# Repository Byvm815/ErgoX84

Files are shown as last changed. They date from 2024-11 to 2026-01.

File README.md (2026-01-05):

# ErgoX Keyboard

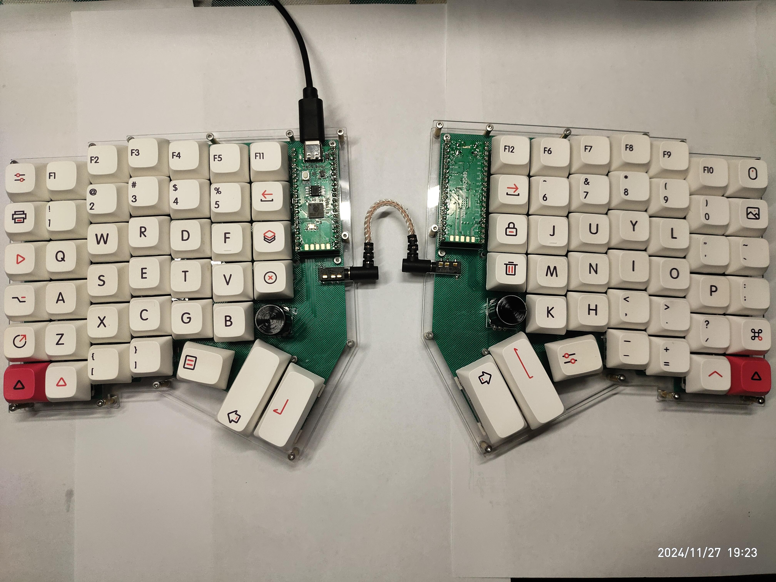
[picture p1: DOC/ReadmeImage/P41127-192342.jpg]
Preview


## BOM Summary

| Product | Count |
|---|---|
| RP2040 type-c Board | 2 |
| Switch | 82 |
| Switch Connector | 82 |
| EC11 Encoder | 2 |
| 1N4148WS T4 | 84 |
| TRRS Cable | 1 |
| TRRS Connector | 2 |
| 2.54-1*20 Connector Female | 4 |
| Switch Board | 2 |
| Bottom Board | 2 |
| Stabilizer 2U | 6 |
| M2 * 3mm Copper Column | 16 |
| M2 * 8mm Copper Column | 50 |
| M2 * 3mm Screw | 132 |

Key caps:

| Key Cap Type  | Count |
|---|---|
| 1U | 68 |
| 1.25U | 4 |
| 1.5U | 2 |
| 1.75U | 2 |
| 2U | 4 |
| 2.25U | 2 |
| EC11 knob cap | 2 |

## Layout

Edited using [Keyboard-Layout-Editor.com](https://keyboard-layout-editor.com/)

Layout files:

- for generating `vial.json`: [keyboard-layout-full-vial-12r7c.json](./keyboard-layout-full-vial-12r7c.json)
- for designing PCB and Case: [keyboard-layout-left.json](./keyboard-layout-left.json)

## Case

Generated using [Plate & Case Builder](http://builder.swillkb.com/), and then edited
using [LibreCAD](https://github.com/LibreCAD/LibreCAD).

Files:

- [Switch board](./case/switch.dxf)
- [Bottom board](./case/bottom.dxf)
- [PCB border and document](./case/pcb.dxf) (only used for PCB designing)

```plaintext
---------------------------- switch board
  | 8mm copper column
  |  ------------------- PCB
  |   | 3mm copper column
---------------------------- bottom board
```

## PCB

Designed using [JLC EDA](https://lceda.cn/editor).

PCB Project: [https://oshwhub.com/lqlklu/ergox](https://oshwhub.com/lqlklu/ergox)

## Firmware

Based on [RMK](https://github.com/HaoboGu/rmk/).

- [./firmware/ergox_conf](./firmware/ergox_conf): using `keyboard.toml` config file, works well
- [./firmware/ergox_rs](./firmware/ergox_rs): using rust code, for testing and do not work now

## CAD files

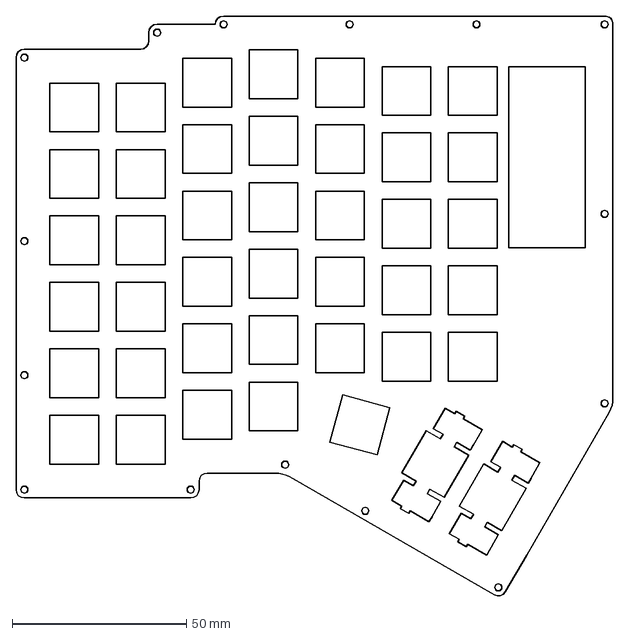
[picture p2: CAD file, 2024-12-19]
case/Switch_ErgoX84_2024-12-09.dxf
171.2 x 166.6 mm

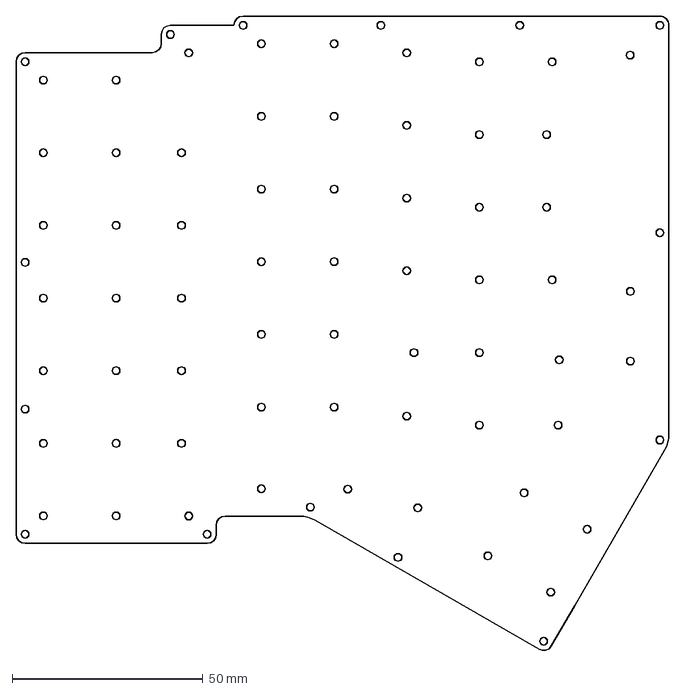
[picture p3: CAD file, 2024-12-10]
case/Bottom_ErgoX84_2024-12-09.dxf
171.2 x 166.6 mm

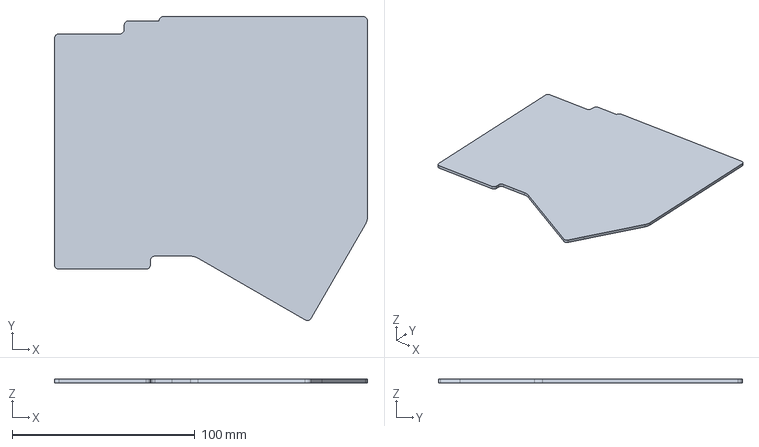
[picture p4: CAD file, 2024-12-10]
case/PCB_ErgoX84_2024-12-09.FCStd
171.2 x 166.3 x 2.00 mm

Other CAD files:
case/PCB_ErgoX84_2024-12-09.dxf

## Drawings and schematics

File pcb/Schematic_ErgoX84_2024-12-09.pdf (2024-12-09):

All document translations are completed by ChatGPT and are for reference only.

L | R

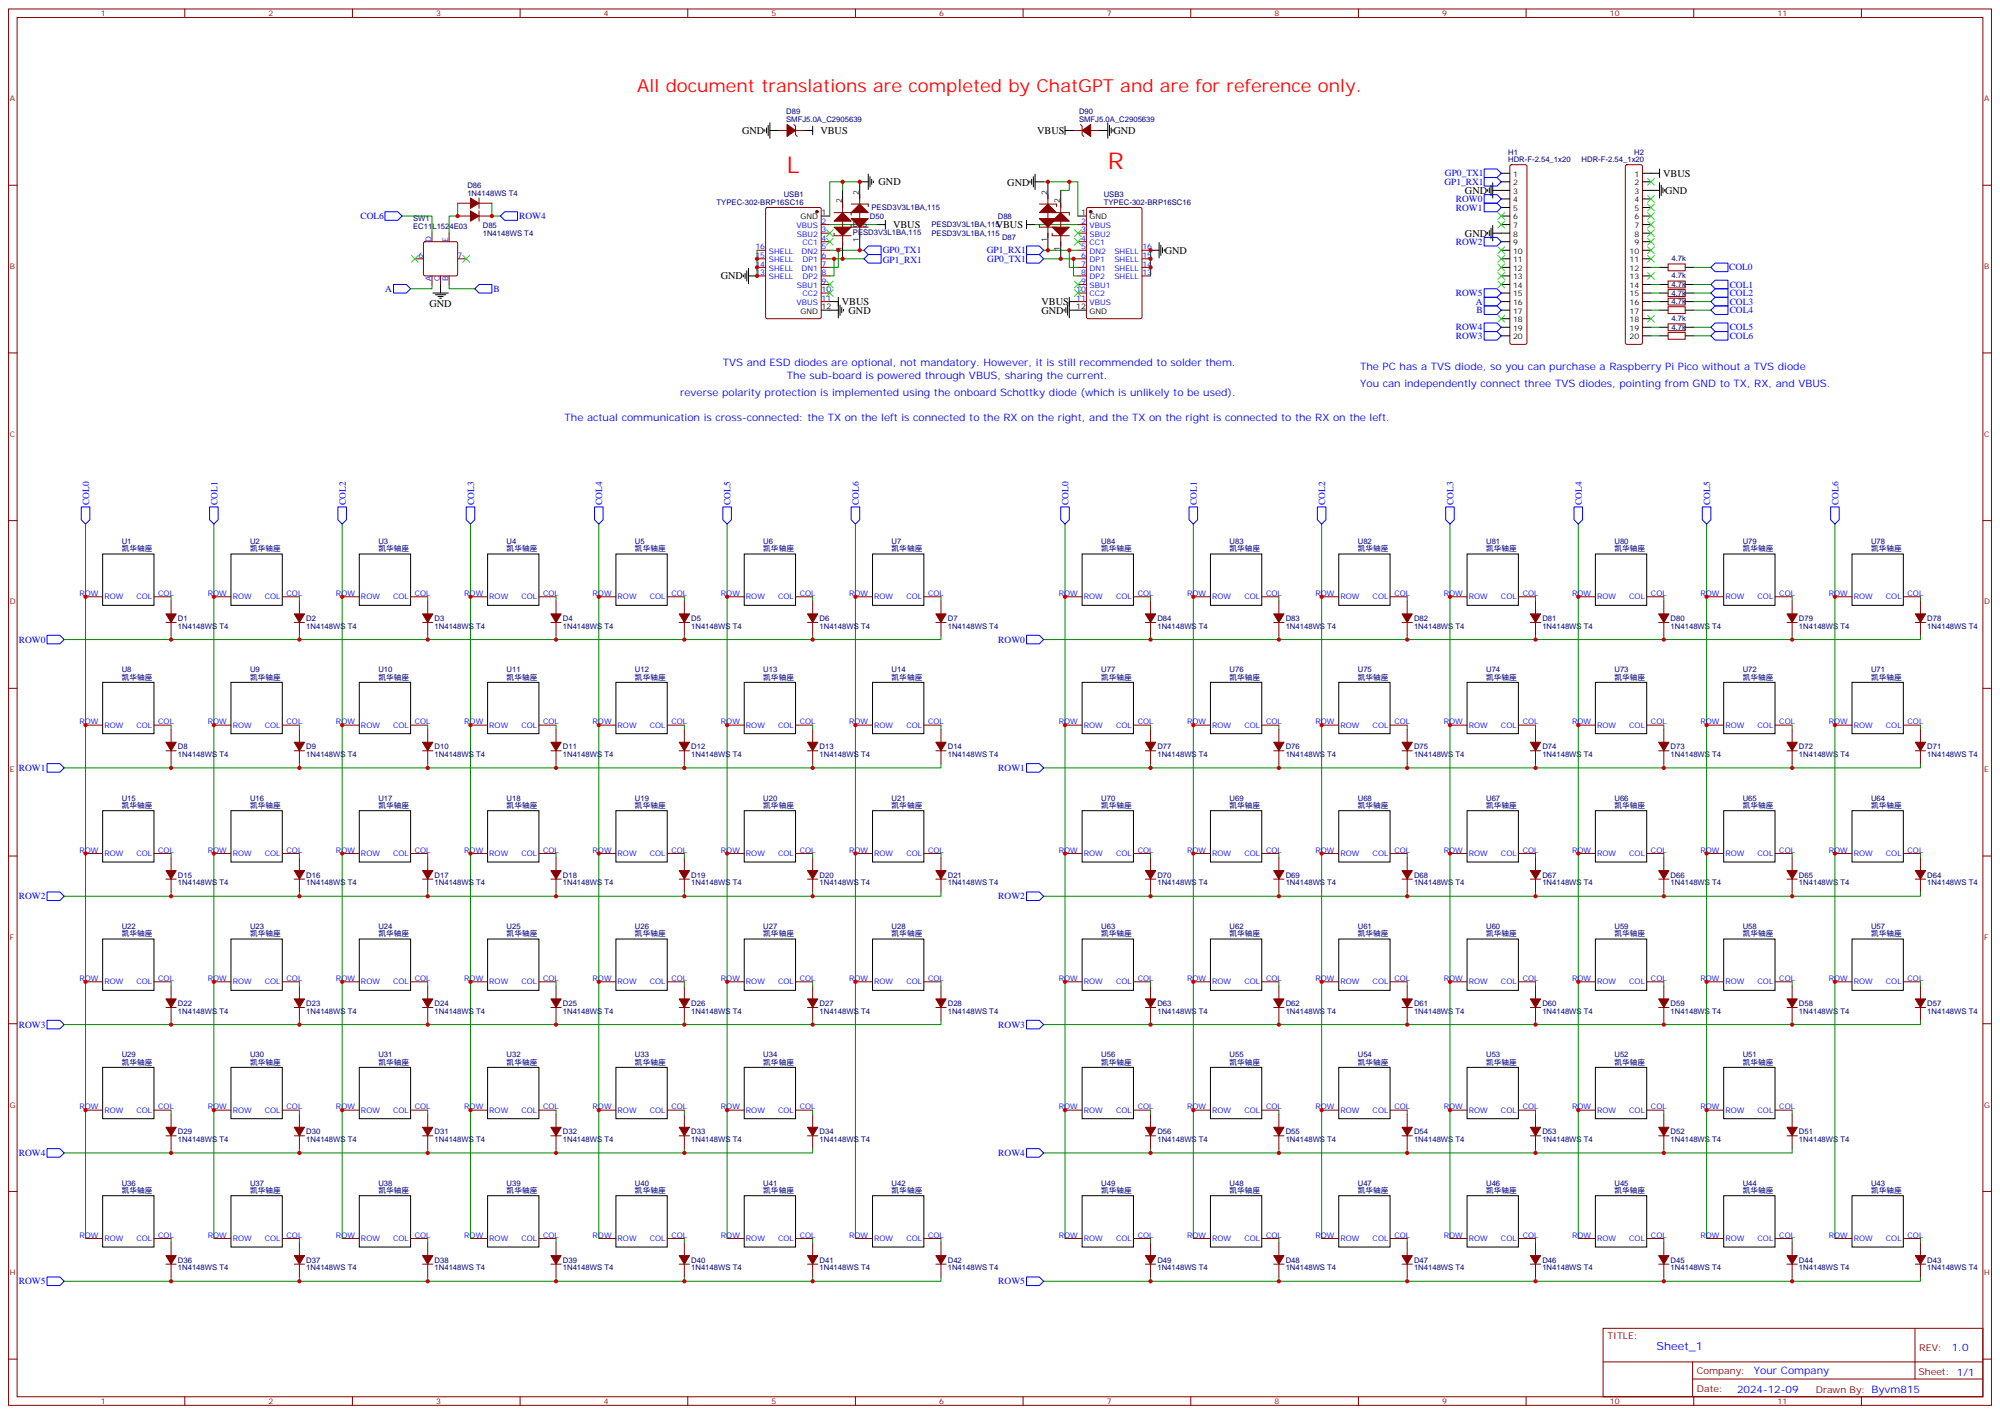
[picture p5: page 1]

TVS and ESD diodes are optional, not mandatory. However, it is still recommended to solder them.

The PC has a TVS diode, so you can purchase a Raspberry Pi Pico without a TVS diode
You can independently connect three TVS diodes, pointing from GND to TX, RX, and VBUS.

The sub-board is powered through VBUS, sharing the current.

reverse polarity protection is implemented using the onboard Schottky diode (which is unlikely to be used).

The actual communication is cross-connected: the TX on the left is connected to the RX on the right, and the TX on the right is connected to the RX on the left.

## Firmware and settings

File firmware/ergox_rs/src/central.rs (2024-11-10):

#![no_main]
#![no_std]

#[macro_use]
mod keymap;
#[macro_use]
mod macros;
mod vial;

use crate::keymap::{COL, NUM_LAYER, ROW};
use defmt::*;
use defmt_rtt as _;
use embassy_executor::Spawner;
use embassy_futures::join::join;
use embassy_rp::{
    bind_interrupts,
    flash::{Async, Flash},
    gpio::{AnyPin, Input, Output},
    peripherals::{self, UART0, USB},
    uart::{self, BufferedUart},
    usb::{Driver, InterruptHandler},
};
// use embassy_rp::flash::Blocking;
use panic_probe as _;
use rmk::{
    config::{KeyboardUsbConfig, RmkConfig, VialConfig},
    split::{
        central::{run_peripheral_monitor, run_rmk_split_central},
        SPLIT_MESSAGE_MAX_SIZE,
    },
};
use static_cell::StaticCell;
use vial::{VIAL_KEYBOARD_DEF, VIAL_KEYBOARD_ID};

bind_interrupts!(struct Irqs {
    USBCTRL_IRQ => InterruptHandler<USB>;
    UART0_IRQ => uart::BufferedInterruptHandler<UART0>;
});

const FLASH_SIZE: usize = 2 * 1024 * 1024;

#[embassy_executor::main]
async fn main(spawner: Spawner) {
    info!("RMK start!");
    // Initialize peripherals
    let p = embassy_rp::init(Default::default());

    // Create the usb driver, from the HAL
    let driver = Driver::new(p.USB, Irqs);

    // Pin config
    let (input_pins, output_pins) =
        config_matrix_pins_rp!(peripherals: p,
            input: [PIN_2, PIN_3, PIN_6, PIN_15, PIN_14, PIN_11],
            output: [PIN_22, PIN_21, PIN_20, PIN_19, PIN_18, PIN_17, PIN_16]);

    // Use internal flash to emulate eeprom
    // Both blocking and async flash are support, use different API
    // let flash = Flash::<_, Blocking, FLASH_SIZE>::new_blocking(p.FLASH);
    let flash = Flash::<_, Async, FLASH_SIZE>::new(p.FLASH, p.DMA_CH0);

    let keyboard_usb_config = KeyboardUsbConfig {
        vid: 0x4c4b,
        pid: 0x4643,
        manufacturer: "lqlklu",
        product_name: "RMK Keyboard",
        serial_number: "vial:f64c2b3c:000001",
    };

    let vial_config = VialConfig::new(VIAL_KEYBOARD_ID, VIAL_KEYBOARD_DEF);

    let keyboard_config = RmkConfig {
        usb_config: keyboard_usb_config,
        vial_config,
        ..Default::default()
    };

    static TX_BUF: StaticCell<[u8; SPLIT_MESSAGE_MAX_SIZE]> = StaticCell::new();
    let tx_buf = &mut TX_BUF.init([0; SPLIT_MESSAGE_MAX_SIZE])[..];
    static RX_BUF: StaticCell<[u8; SPLIT_MESSAGE_MAX_SIZE]> = StaticCell::new();
    let rx_buf = &mut RX_BUF.init([0; SPLIT_MESSAGE_MAX_SIZE])[..];
    let uart_receiver = BufferedUart::new(
        p.UART0,
        Irqs,
        p.PIN_0,
        p.PIN_1,
        tx_buf,
        rx_buf,
        uart::Config::default(),
    );

    // Start serving
    join(
        run_rmk_split_central::<
            Input<'_>,
            Output<'_>,
            Driver<'_, USB>,
            Flash<peripherals::FLASH, Async, FLASH_SIZE>,
            ROW,
            COL,
            6,
            7,
            0,
            0,
            NUM_LAYER,
        >(
            input_pins,
            output_pins,
            driver,
            flash,
            &mut keymap::get_default_keymap(),
            keyboard_config,
            spawner,
        ),
        run_peripheral_monitor::<6, 7, 6, 0, _>(0, uart_receiver),
    )
        .await;
}

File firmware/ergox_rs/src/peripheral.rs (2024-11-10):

#![no_main]
#![no_std]

#[macro_use]
mod macros;

use defmt::*;
use defmt_rtt as _;
use embassy_executor::Spawner;
use embassy_rp::{
    bind_interrupts,
    gpio::{AnyPin, Input, Output},
    peripherals::{UART0, USB},
    uart::{self, BufferedUart},
    usb::InterruptHandler,
};
use panic_probe as _;
use rmk::split::{peripheral::run_rmk_split_peripheral, SPLIT_MESSAGE_MAX_SIZE};
use static_cell::StaticCell;

bind_interrupts!(struct Irqs {
    USBCTRL_IRQ => InterruptHandler<USB>;
    UART0_IRQ => uart::BufferedInterruptHandler<UART0>;
});

#[embassy_executor::main]
async fn main(_spawner: Spawner) {
    info!("RMK start!");
    // Initialize peripherals
    let p = embassy_rp::init(Default::default());

    // Pin config
    let (input_pins, output_pins) =
        config_matrix_pins_rp!(peripherals: p,
            input: [PIN_2, PIN_3, PIN_6, PIN_15, PIN_14, PIN_11],
            output: [PIN_16 ,PIN_17, PIN_18, PIN_19, PIN_20, PIN_21, PIN_22]);

    static TX_BUF: StaticCell<[u8; SPLIT_MESSAGE_MAX_SIZE]> = StaticCell::new();
    let tx_buf = &mut TX_BUF.init([0; SPLIT_MESSAGE_MAX_SIZE])[..];
    static RX_BUF: StaticCell<[u8; SPLIT_MESSAGE_MAX_SIZE]> = StaticCell::new();
    let rx_buf = &mut RX_BUF.init([0; SPLIT_MESSAGE_MAX_SIZE])[..];
    let uart_instance = BufferedUart::new(
        p.UART0,
        Irqs,
        p.PIN_0,
        p.PIN_1,
        tx_buf,
        rx_buf,
        uart::Config::default(),
    );

    // Start serving
    run_rmk_split_peripheral::<Input<'_>, Output<'_>, _, 6, 7>(
        input_pins,
        output_pins,
        uart_instance,
    )
        .await;
}

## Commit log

2024-11-10 update stabilizer, add a pcb hold
    [bottom.dxf, pcb.dxf, switch.dxf]
2024-11-10 add pcb files
    [BOM_ErgoX_2024-11-10.csv]
2024-11-21 change to be 1U layout
    [bottom.dxf, switch.dxf]
2024-11-28 Use wires to connect GND instead of copper pour.
2024-11-28 Add more mounting holes to the outermost part of the case (as they were removed due to the 1U modification).
    [#bottom.dxf, switch.dxf]
2024-12-09 Clear Old file
    [#bottom.dxf, BOM_ErgoX_2024-11-10.csv, bottom.dxf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]
2024-12-09 add ErgoX84 file
    [PCB_ErgoX84_2024-12-09.dxf]
2024-12-09 PCB: add open source hardware logo
    [PCB_ErgoX84_2024-12-09.dxf]
2024-12-09 Case: replace, use metric millimeter units
    [PCB_ErgoX84_2024-12-09.dxf]
2024-12-10 Case: add switch and bottom case file
    [Bottom_ErgoX84_2024-12-09.dxf, PCB_ErgoX84_2024-12-09.FCStd, Switch_ErgoX84_2024-12-09.dxf]
2024-12-19 Case: Fix `switch.dxf` to make it compatible with Taobao satellite switches, only modifying the DXF file.
    [Switch_ErgoX84_2024-12-09.dxf]
